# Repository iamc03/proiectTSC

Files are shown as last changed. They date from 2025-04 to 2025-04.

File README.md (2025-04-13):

# Proiect TSC
 ## Diagrama Bloc
 schema bloc

 ## Bill of Materials
 | Component       | Datasheet       | Link           |
 |-----------------|-----------------|----------------|
 | ESP32-C6-WROOM-1-N8 | - | https://www.snapeda.com/parts/ESP32-C6-WROOM-1-N8/Espressif+Systems/view-part/?ref=eda |
 | CPH3225A | - | https://www.snapeda.com/parts/CPH3225A/Seiko+Instruments/view-part/?ref=eda |
 | DS3231SN# | - | https://www.snapeda.com/parts/DS3231SN%23/Analog+Devices/view-part/?ref=eda |
 | MAX17048G+T10 | - | https://www.snapeda.com/parts/MAX17048G+T10/Analog+Devices/view-part/?ref=eda|
 | MBR0530 | - | https://www.snapeda.com/parts/MBR0530/Onsemi/view-part/?ref=eda |
 | PGB1010603MR | - | https://www.snapeda.com/parts/PGB1010603MR/Littelfuse/view-part/?ref=eda |
 | USBLC6-2SC6Y | - | https://www.snapeda.com/parts/USBLC6-2SC6Y/STMicroelectronics/view-part/?ref=eda |
 | W25Q512JVEIQ | - | https://www.snapeda.com/parts/W25Q512JVEIQ/Winbond+Electronics/view-part/?ref=eda |
 | 640-USB4110-GF-A | - | https://www.mouser.co.uk/ProductDetail/GCT/USB4110-GF-A?qs=KUoIvG%2F9IlYiZvIXQjyJeA%3D%3D |
 | PGB1010603MR | - | https://www.snapeda.com/parts/PGB1010603MR/Littelfuse/view-part/?ref=snap |
 | BUTTONS | - | https://industry.panasonic.com/global/en/products/control/switch/light-touch/number/evqpuj02k |
 | C (1-10) | - | https://componentsearchengine.com/part-view/CC0402MRX5R5BB106/YAGEO |
 | LED | - | https://www.snapeda.com/parts/KP-1608SURCK/Kingbright/view-part/?ref=search&t=LED%200603 |
 | D (1-12) | - | https://www.snapeda.com/parts/PGB1010603MR/Littelfuse/view-part/?ref=eda |
 | R (1-15) | - | https://componentsearchengine.com/part-view/R0402%201%25%20100%20K%20(RC0402FR-07100KL)/YAGEO |
 | Test Pads | - | - |
   
## Funcționalitate hardware
### Alimentare și încărcare
Conector USB + MCP73831: Permite încărcarea unei baterii LiPo prin USB.

LDO (ME6211 sau similar): Reglează tensiunea la 3.3V pentru alimentarea circuitului digital.

Condensatori de decuplare: Plasați strategic pentru stabilizarea alimentării.

### ESP32-C6
Modul WiFi/BLE cu capabilități de conectare și procesare date.

Flash: 4MB / RAM: 512KB.

GPIO multiple folosite pentru comunicații (SPI, I2C) și control periferice.

### E-Ink Display
Controlat prin SPI.

GPIO-uri adiționale pentru semnale de control (busy, reset).

### Protecții
Diodă Schottky (ex: MBR0530) pentru protecție polaritate inversă.

PTC resetabil pentru protecție curent.

### EEPROM / MEMS
EEPROM pentru păstrarea datelor între cicluri de alimentare (presupus U3).

MAX17048 pentru monitorizarea nivelului bateriei (comunicare I2C).

| Pin ESP32-C6 |	Funcție hardware |
|---|---|
| IO0 |	GPIO / Boot	|
| IO1 |	UART TX |
| IO2 |	UART RX	|
| IO3 |	GPIO	|
| IO4 | GPIO	|
| IO5 |	GPIO	|
| IO6 |	GPIO	|
| IO7 |	GPIO	|
| IO8 |	GPIO	|
| IO9 |	SPI Flash – IO2 |
| IO10 | 	SPI Flash – IO3 |
| IO11 |	SPI Flash – SCK |
| IO12 |	SPI Flash – CS |
| IO13 |	SPI Flash – IO1 |
| IO14 |	SPI Flash – IO0 |
| IO15 |	I2C SDA |
| IO16 |	I2C SCL |
| IO17 |	SPI Display – DC |
| IO18 |	SPI Display – RST |
| IO19 |	SPI Display – CS |
| IO20 |	SPI Display – CLK |
| IO21 |	SPI Display – MOSI |
| IO22 |	SPI Display – BUSY |
| IO23 |	SPI ESD / Qwiic |

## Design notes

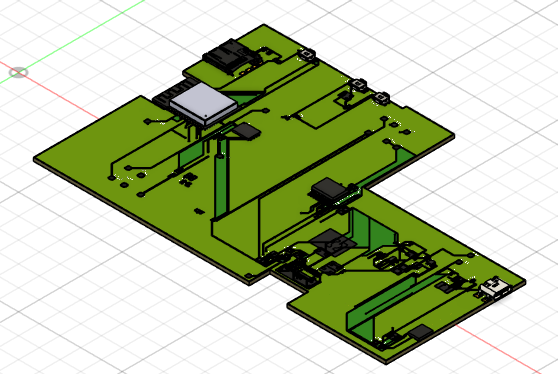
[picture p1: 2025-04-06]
Images/placa.png

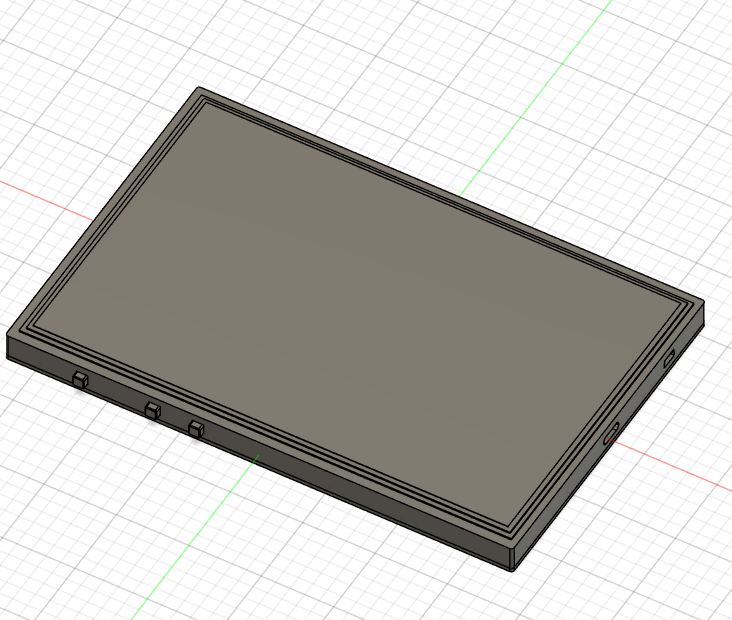
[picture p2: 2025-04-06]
Images/openbook.png

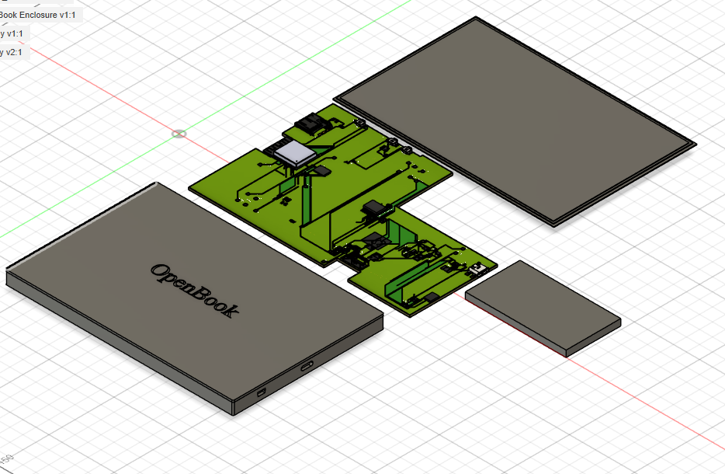
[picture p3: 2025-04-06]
Images/exploded.png

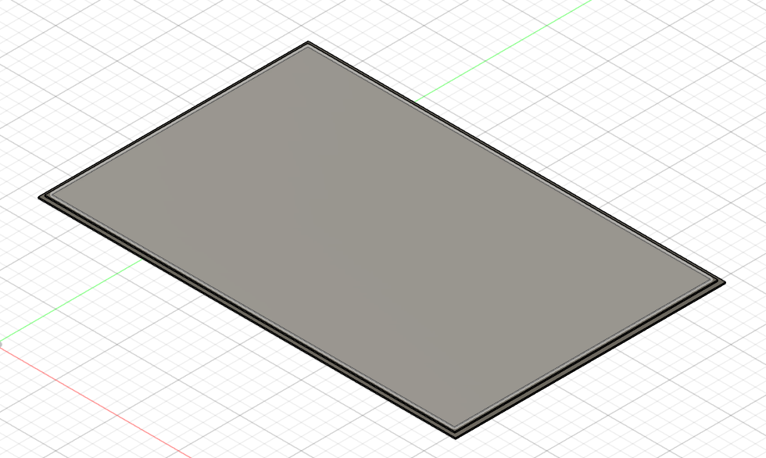
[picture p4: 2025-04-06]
Images/display.png

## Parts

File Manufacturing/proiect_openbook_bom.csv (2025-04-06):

Qty | Value | Device | Package | Parts | Description | ARROW_PART_NUMBER | ARROW_PRICE-STOCK | AVAILABILITY | CENTROID_NOT_SPECIFIED | CHECK_PRICES | COPYRIGHT | DATASHEET | DESCRIPTION | DIGIKEY_DESCRIPTION | DIGIKEY_PART_NUMBER | HEIGHT | LEAD_FREE | MANUFACTURER_NAME | MANUFACTURER_PART_NUMBER | MF | MFR_NAME | MOUSER_PART_NUMBER | MOUSER_PRICE-STOCK | MOUSER_TESTING_PART_NUMBER | MOUSER_TESTING_PRICE-STOCK | MP | MPN | PACKAGE | POPULARITY | PREFIX | PRICE | PROD_ID | PURCHASE-URL | ROHS | SNAPEDA_LINK | SPICEMODEL | SPICEPREFIX | TEMPERATURE_RANGE_HIGH | TEMPERATURE_RANGE_LOW | TP_SIGNAL_NAME | VALUE
1 |  | ADAFRUIT_LEDCHIP-LED0603 | ADAFRUIT_CHIP-LED0603 | LED1 | LED
1 |  | SJ | SJ | SJ1 | SMD solder JUMPER |  |  |  |  |  |  |  |  |  |  |  |  |  |  |  |  |  |  |  |  |  |  |  | 3
1 | 0.1uF/50V | ESP32_WROVER_EAGLE-LTSPICE_CC0402 | ESP32_WROVER_EAGLE-LTSPICE_C0402 | C18 | CAPACITOR, European symbol |  |  |  |  |  |  |  |  |  |  |  |  |  |  |  |  |  |  |  |  |  |  |  |  |  |  |  |  |  |  | NONE | C
1 | 0.47 | ESP32_WROVER_EAGLE-LTSPICE_RR0402 | ESP32_WROVER_EAGLE-LTSPICE_R0402 | R9 | RESISTOR, European symbol |  |  |  |  |  |  |  |  |  |  |  |  |  |  |  |  |  |  |  |  |  |  |  |  |  |  |  |  |  |  | NONE | R
1 | 100K | ESP32_WROVER_EAGLE-LTSPICE_RR0402 | ESP32_WROVER_EAGLE-LTSPICE_R0402 | R4 | RESISTOR, European symbol |  |  |  |  |  |  |  |  |  |  |  |  |  |  |  |  |  |  |  |  |  |  |  |  |  |  |  |  |  |  | NONE | R
8 | 100nF | ESP32_WROVER_EAGLE-LTSPICE_CC0402 | ESP32_WROVER_EAGLE-LTSPICE_C0402 | C1, C6, C21, C22, C23, C25, C26, C27 | CAPACITOR, European symbol |  |  |  |  |  |  |  |  |  |  |  |  |  |  |  |  |  |  |  |  |  |  |  |  |  |  |  |  |  |  | NONE | C
1 | 100uF | RCL_CPOL-EUCT3528 | RCL_CT3528 | C5 | POLARIZED CAPACITOR, European symbol |  |  |  |  |  |  |  |  |  |  |  |  |  |  |  |  |  |  |  |  |  |  |  | 0 |  |  |  |  |  |  |  | C
16 | 10K | ESP32_WROVER_EAGLE-LTSPICE_RR0402 | ESP32_WROVER_EAGLE-LTSPICE_R0402 | R5, R8, R12, R13, R14, R15, R16, R17, R19, R20, R21, R22, R23, R24, R25, R26 | RESISTOR, European symbol |  |  |  |  |  |  |  |  |  |  |  |  |  |  |  |  |  |  |  |  |  |  |  |  |  |  |  |  |  |  | NONE | R
1 | 10uF | ESP32_WROVER_EAGLE-LTSPICE_CC0402 | ESP32_WROVER_EAGLE-LTSPICE_C0402 | C10 | CAPACITOR, European symbol |  |  |  |  |  |  |  |  |  |  |  |  |  |  |  |  |  |  |  |  |  |  |  |  |  |  |  |  |  |  | NONE | C
1 | 112A-TAAR-R03_ATTEND | 112A-TAAR-R03_ATTEND | 112ATAARR03ATTEND | J2 | Micro SD Card Socket, Push-Push Type, Top Mount, SMT, H=1.83mm, 10u |  |  |  |  |  |  |  | Micro SD Card Socket | Push-Push Type | Top Mount | SMT | H=1.83mm | 10u |  |  | 1.9mm |  | ATTEND | 112A-TAAR-R03 ATTEND
1 | 15 | ESP32_WROVER_EAGLE-LTSPICE_RR0402 | ESP32_WROVER_EAGLE-LTSPICE_R0402 | R18 | RESISTOR, European symbol |  |  |  |  |  |  |  |  |  |  |  |  |  |  |  |  |  |  |  |  |  |  |  |  |  |  |  |  |  |  | NONE | R
1 | 1uF | ESP32_WROVER_EAGLE-LTSPICE_CC0402 | ESP32_WROVER_EAGLE-LTSPICE_C0402 | C24 | CAPACITOR, European symbol |  |  |  |  |  |  |  |  |  |  |  |  |  |  |  |  |  |  |  |  |  |  |  |  |  |  |  |  |  |  | NONE | C
9 | 1uF/50V | ESP32_WROVER_EAGLE-LTSPICE_CC0402 | ESP32_WROVER_EAGLE-LTSPICE_C0402 | C11, C12, C13, C14, C15, C16, C17, C19, C20 | CAPACITOR, European symbol |  |  |  |  |  |  |  |  |  |  |  |  |  |  |  |  |  |  |  |  |  |  |  |  |  |  |  |  |  |  | NONE | C
1 | 2.2 | ESP32_WROVER_EAGLE-LTSPICE_RR0402 | ESP32_WROVER_EAGLE-LTSPICE_R0402 | R10 | RESISTOR, European symbol |  |  |  |  |  |  |  |  |  |  |  |  |  |  |  |  |  |  |  |  |  |  |  |  |  |  |  |  |  |  | NONE | R
1 | 200 | ESP32_WROVER_EAGLE-LTSPICE_RR0402 | ESP32_WROVER_EAGLE-LTSPICE_R0402 | R6 | RESISTOR, European symbol |  |  |  |  |  |  |  |  |  |  |  |  |  |  |  |  |  |  |  |  |  |  |  |  |  |  |  |  |  |  | NONE | R
2 | 20V/4.2A/52mO/1.4W | ESP32_WROVER_SPARKFUN-DISCRETESEMI_MOSFET_PCH-DMG2305UX-7 | ESP32_WROVER_SPARKFUN-DISCRETESEMI_SOT23-3 | Q1, Q3 | P-channel MOSFETs |  |  |  |  |  |  |  |  |  |  |  |  |  |  |  |  |  |  |  |  |  |  |  |  |  |  | TRAN-14388 |  |  |  |  |  |  |  |  | 20V/4.2A/52mO/1.4W
1 | 2K | ESP32_WROVER_EAGLE-LTSPICE_RR0402 | ESP32_WROVER_EAGLE-LTSPICE_R0402 | R7 | RESISTOR, European symbol |  |  |  |  |  |  |  |  |  |  |  |  |  |  |  |  |  |  |  |  |  |  |  |  |  |  |  |  |  |  | NONE | R
2 | 4.7uF | EAGLE-LTSPICE_CC0402 | EAGLE-LTSPICE_C0402 | C3, C4 | CAPACITOR, European symbol |  |  |  |  |  |  |  |  |  |  |  |  |  |  |  |  |  |  |  |  |  |  |  |  |  |  |  |  |  |  | NONE | C
3 | 4.7uF | ESP32_WROVER_EAGLE-LTSPICE_CC0402 | ESP32_WROVER_EAGLE-LTSPICE_C0402 | C2, C7, C8 | CAPACITOR, European symbol |  |  |  |  |  |  |  |  |  |  |  |  |  |  |  |  |  |  |  |  |  |  |  |  |  |  |  |  |  |  | NONE | C
1 | 4.7uF/25V | ESP32_WROVER_EAGLE-LTSPICE_CC0402 | ESP32_WROVER_EAGLE-LTSPICE_C0402 | C9 | CAPACITOR, European symbol |  |  |  |  |  |  |  |  |  |  |  |  |  |  |  |  |  |  |  |  |  |  |  |  |  |  |  |  |  |  | NONE | C
2 | 5k1 | ESP32_WROVER_EAGLE-LTSPICE_RR0402 | ESP32_WROVER_EAGLE-LTSPICE_R0402 | R2, R3 | RESISTOR, European symbol |  |  |  |  |  |  |  |  |  |  |  |  |  |  |  |  |  |  |  |  |  |  |  |  |  |  |  |  |  |  | NONE | R
1 | 68uH | 744043680IND_4828-WE-TPC_WRE | IND_4828-WE-TPC_WRE | L1 |  |  |  |  |  |  | Copyright (C) 2024 Ultra Librarian. All rights reserved. |  |  |  |  |  |  |  | 744043680 |  | Wurth Electronics
1 | BD5229G-TR | BD5229G-TR | SOT95P280X125-5N | IC2 | Voltage Detector with Adjustable Delay Time: CMOS processes are utilized to develop high precision, low current consumption CMOS reset ICs that allow arbitrary setting of the delay time. The extensive lineup includes both Nch Open Drain and CMOS output types in a wide range of detection voltages (from 2.3V to 6.0V, in 0.1V steps), enabling selection of the ideal solution based on customer requirements. In addition, the entire series is of course both lead-free and RoHS-compliant. |  |  |  |  |  |  |  | Voltage Detector with Adjustable Delay Time: CMOS processes are utilized to develop high precision | low current consumption CMOS reset ICs that allow arbitrary setting of the delay time. The extensive lineup includes both Nch Open Drain and CMOS output types in a wide range of detection voltages (from 2.3V to 6.0V | in 0.1V steps) | enabling selection of the ideal solution based on customer requirements. In addition | the entire series is of course both lead-free and RoHS-compliant. |  |  | 1.25mm |  | ROHM Semiconductor | BD5229G-TR |  |  | 755-BD5229G-TR | https://www.mouser.co.uk/ProductDetail/ROHM-Semiconductor/BD5229G-TR?qs=4kLU8WoGk0vvnhrrYwdszw%3D%3D
3 | BUTTON_CUSYOMV1 | BUTTON_CUSYOMV1 | MYBUTTON | U$1, U$2, U$3
1 | CPH3225A | CPH3225A | CAPCP3225X100N | C28 | Cap 0.011F 3.3V 1210 Flat Check availability |  |  | Not in stock |  | https://www.snapeda.com/parts/CPH3225A/Seiko+Instruments/view-part/?ref=eda |  |  | 11 mF (EDLC) Supercapacitor 3.3 V 1210 (3225 Metric) - - |  |  |  |  |  |  | Seiko Instruments |  |  |  |  |  | CPH3225A |  | 1210 Seiko |  |  | None |  | https://www.snapeda.com/api/url_track_click_mouser/?unipart_id=562593&manufacturer=Seiko Instruments&part_name=CPH3225A&search_term=None |  | https://www.snapeda.com/parts/CPH3225A/Seiko+Instruments/view-part/?ref=snap
1 | DS3231SN# | DS3231SN# | SOIC127P1032X265-16N | U5 | Real Time Clock Serial 16-Pin SOIC W T/R Check availability |  |  | In Stock |  | https://www.snapeda.com/parts/DS3231SN%23/Analog+Devices/view-part/?ref=eda |  |  | Extremely Accurate I²C-Integrated RTC/TCXO/Crystal |  |  |  |  |  |  | Analog Devices |  |  |  |  |  | DS3231SN# |  | SOIC-16 Maxim |  |  | None |  | https://www.snapeda.com/api/url_track_click_mouser/?unipart_id=99048&manufacturer=Analog Devices&part_name=DS3231SN#&search_term=None |  | https://www.snapeda.com/parts/DS3231SN%23/Analog+Devices/view-part/?ref=snap
1 | ESP32-C6-WROOM-1-N8 | ESP32-C6-WROOM-1-N8 | XCVR_ESP32-C6-WROOM-1-N8 | U1 | Check availability |  |  | In Stock |  | https://www.snapeda.com/parts/ESP32-C6-WROOM-1-N8/Espressif+Systems/view-part/?ref=eda |  |  | Multiprotocol Modules ESP32-C6 module | Wi-Fi 6 in 2.4 GHz band | Bluetooth 5 | Zigbee 3.0 and Thread. ESP34-WROOM Compatible - ENGINEERING SAMPLE |  |  |  |  |  |  | Espressif Systems |  |  |  |  |  | ESP32-C6-WROOM-1-N8 |  | None |  |  | None |  |  |  | https://www.snapeda.com/parts/ESP32-C6-WROOM-1-N8/Espressif+Systems/view-part/?ref=snap
1 | ESP32C6_VARISTORCN1812 | ESP32C6_VARISTORCN1812 | ESP32C6_VARISTOR_CT/CN1812 | R1 | VARISTOR |  |  |  |  |  |  |  |  |  |  |  |  |  |  |  |  |  |  |  |  |  |  |  | 0
2 | ESP32_WROVER_AVX---SD0805S020S1R0_AVX_SD0805S020S1R0_0_0AVX_SD0805S020S1R0_0_0 | ESP32_WROVER_AVX---SD0805S020S1R0_AVX_SD0805S020S1R0_0_0AVX_SD0805S020S1R0_0_0 | ESP32_WROVER_AVX---SD0805S020S1R0_AVX_SD0805S020S1R0_0 | D2, D6 | Schottky Barrier Rectifier Diode |  |  |  | No |  |  | http://datasheets.avx.com/schottky.pdf |  | DIODE SCHOTTKY 20V 1A 0805 | 478-7800-1-ND |  | yes |  |  | AVX |  | 581-SD0805S020S1R0 |  |  |  |  |  | 0805 (2012 metric) |  | D |  |  |  | yes |  |  |  | +125°C | -55°C
1 | ESP32_WROVER_BME680_BME680 | ESP32_WROVER_BME680_BME680 | ESP32_WROVER_BME680_PSON80P300X300X100-8N | U3 | Integrated Environmental Unit |  |  | Unavailable |  |  |  |  | Integrated Environmental Unit |  |  |  |  |  |  | Bosch Sensortec |  |  |  |  |  | BME680 |  | LGA-8 Bosch Tools |  |  | None
1 | ESP32_WROVER_SPARKFUN-IC-POWER_MCP73831 | ESP32_WROVER_SPARKFUN-IC-POWER_MCP73831 | ESP32_WROVER_SPARKFUN-IC-POWER_SOT23-5 | U2 | MCP73831T Li-Ion, Li-Pol Controller |  |  |  |  |  |  |  |  |  |  |  |  |  |  |  |  |  |  |  |  |  |  |  |  |  |  | IC-09995
1 | FH34SRJ-24S-0.5SH_99_ | FH34SRJ-24S-0.5SH_99_ | FH34SRJ24S05SH99 | J3 | (0.50mm) Surface Mount, Right Angle |  |  |  |  |  |  |  | 24 Position FFC | FPC Connector Contacts | (0.50mm) Surface Mount | Right Angle |  |  | 1.1mm |  | Hirose | FH34SRJ-24S-0.5SH(99) |  |  | 798-FH34SRJ24S05SH99 | https://www.mouser.co.uk/ProductDetail/Hirose-Connector/FH34SRJ-24S-0.5SH99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
1 | MAX17048G+T10 | MAX17048G+T10 | SON50P200X200X80-9N | U4 | Check availability |  |  | In Stock |  | https://www.snapeda.com/parts/MAX17048G+T10/Analog+Devices/view-part/?ref=eda |  |  | 3µA 1-Cell/2-Cell Fuel Gauge with ModelGauge |  |  |  |  |  |  | Analog Devices |  |  |  |  |  | MAX17048G+T10 |  | TDFN-8 Maxim |  |  | None |  | https://www.snapeda.com/api/url_track_click_mouser/?unipart_id=329239&manufacturer=Analog Devices&part_name=MAX17048G+T10&search_term=None |  | https://www.snapeda.com/parts/MAX17048G+T10/Analog+Devices/view-part/?ref=snap
3 | MBR0530 | MBR0530 | SOD3716X135N | D3, D4, D5 | ON SEMICONDUCTOR - MBR0530 - DIODE, SCHOTTKY, 0.5A, 30V, SOD-123 |  |  | In Stock |  | https://www.snapeda.com/parts/MBR0530/Onsemi/view-part/?ref=eda |  |  | Diode Schottky 30 V 500mA Surface Mount SOD-123 |  |  |  |  |  |  | ON Semiconductor |  |  |  |  |  | MBR0530 |  | SOD-123-2 ON Semiconductor |  |  | None |  | https://www.snapeda.com/api/url_track_click_mouser/?unipart_id=179458&manufacturer=ON Semiconductor&part_name=MBR0530&search_term=None |  | https://www.snapeda.com/parts/MBR0530/Onsemi/view-part/?ref=snap
6 | PGB1010603MR | PGB1010603MR | DIOC1608X36N | D7, D8, D9, D10, D11, D12 | Check availability |  |  | In Stock |  | https://www.snapeda.com/parts/PGB1010603MR/Littelfuse/view-part/?ref=eda |  |  | 150V (Typ) Clamp - Ipp Tvs Diode Surface Mount 0603 (1608 Metric) |  |  |  |  |  |  | Littelfuse Inc. |  |  |  |  |  | PGB1010603MR |  | 0603 Littelfuse Inc. |  |  | None |  | https://www.snapeda.com/api/url_track_click_mouser/?unipart_id=5659453&manufacturer=Littelfuse Inc.&part_name=PGB1010603MR&search_term=None |  | https://www.snapeda.com/parts/PGB1010603MR/Littelfuse/view-part/?ref=snap
1 | QWIIC_RIGHT_ANGLE | QWIIC_CONNECTORJS-1MM | JST04_1MM_RA | J4 | SparkFun I2C Standard Qwiic Connector |  |  |  |  |  |  |  |  |  |  |  |  |  |  |  |  |  |  |  |  |  |  |  |  |  |  | CONN-13694 |  |  |  |  |  |  |  |  | QWIIC_RIGHT_ANGLE
1 | SAMACSYS_PARTS_USB4110-GF-A | SAMACSYS_PARTS_USB4110-GF-A | SAMACSYS_PARTS_USB4110GFA | J1 | CONN USB 2.0 TYPE-C R/A SMT |  |  |  |  |  |  |  | CONN USB 2.0 TYPE-C R/A SMT |  |  | 3.26mm |  | GCT (GLOBAL CONNECTOR TECHNOLOGY) | USB4110-GF-A |  |  | 640-USB4110-GF-A | https://www.mouser.co.uk/ProductDetail/GCT/USB4110-GF-A?qs=KUoIvG%2F9IlYiZvIXQjyJeA%3D%3D
1 | SI1308EDL-T1-GE3 | SI1308EDL-T1-GE3 | SOT65P210X110-3N | Q2 | MOSFET N-Ch 30V 1.5A TrenchFET SC70 Vishay Si1308EDL-T1-GE3 N-channel MOSFET Transistor, 1.5 A, 30 V, 3-Pin SC-70 |  |  | In Stock |  | https://www.snapeda.com/parts/SI1308EDL-T1-GE3/Vishay+Siliconix/view-part/?ref=eda |  |  | Si1308EDL-T1-GE3 N-channel MOSFET Transistor | 1.5 A | 30 V | 3-Pin SC-70 | Siliconix / Vishay SI1308EDL-T1-GE3 |  |  |  |  |  |  | Vishay Siliconix |  |  |  |  |  | SI1308EDL-T1-GE3 |  | SOT-323 Vishay Semiconductor |  |  | None |  | https://www.snapeda.com/api/url_track_click_mouser/?unipart_id=274603&manufacturer=Vishay Siliconix&part_name=SI1308EDL-T1-GE3&search_term=None |  | https://www.snapeda.com/parts/SI1308EDL-T1-GE3/Vishay+Siliconix/view-part/?ref=snap
17 | TPTP20R | TPTP20R | TP20R | TP1, TP2, TP3, TP4, TP5, TP6, TP7, TP9, TP10, TP11, TP12, TP13, TP14, TP15, TP16, TP17, TP18 | Test pad |  |  |  |  |  |  |  |  |  |  |  |  |  |  |  |  |  |  |  |  |  |  |  | 2
1 | USBLC6-2SC6Y | USBLC6-2SC6Y | SOT95P280X145-6N | D1 | Low Cap. ESD Protection Auto SOT-23-6 STMicroelectronics USBLC6-2SC6Y, Dual Uni-Directional TVS Diode Array, 6-Pin SOT-23 |  |  | In Stock |  | https://www.snapeda.com/parts/USBLC6-2SC6Y/STMicroelectronics/view-part/?ref=eda |  |  | 17V Clamp 5A (8/20µs) Ipp Tvs Diode Surface Mount SOT-23-6 |  |  |  |  |  |  | STMicroelectronics |  |  |  |  |  | USBLC6-2SC6Y |  | SOT-23-6 STMicroelectronics |  |  | None |  |  |  | https://www.snapeda.com/parts/USBLC6-2SC6Y/STMicroelectronics/view-part/?ref=snap
1 | W25Q512JVEIQ | W25Q512JVEIQ | SON127P600X800X80-9N | U6 | Check availability |  |  | In Stock |  | https://www.snapeda.com/parts/W25Q512JVEIQ/Winbond+Electronics/view-part/?ref=eda |  |  | FLASH - NOR Memory IC 512Mb (64M x 8) SPI - Quad I/O 133 MHz 8-WSON (8x6) |  |  |  |  |  |  | Winbond Electronics |  |  |  |  |  | W25Q512JVEIQ |  | Package |  |  | None |  |  |  | https://www.snapeda.com/parts/W25Q512JVEIQ/Winbond+Electronics/view-part/?ref=snap
1 | XC6220A331MR-G | XC6220A331MR-G | SOT95P280X120-5N | IC1 | LDO Voltage Regulators |  |  |  |  |  |  |  | LDO Voltage Regulators |  |  | 1.2mm |  | Torex | XC6220A331MR-G |  |  | 865-XC6220A331MR-G | https://www.mouser.co.uk/ProductDetail/Torex-Semiconductor/XC6220A331MR-G?qs=AsjdqWjXhJ8ZSWznL1J0gg%3D%3D

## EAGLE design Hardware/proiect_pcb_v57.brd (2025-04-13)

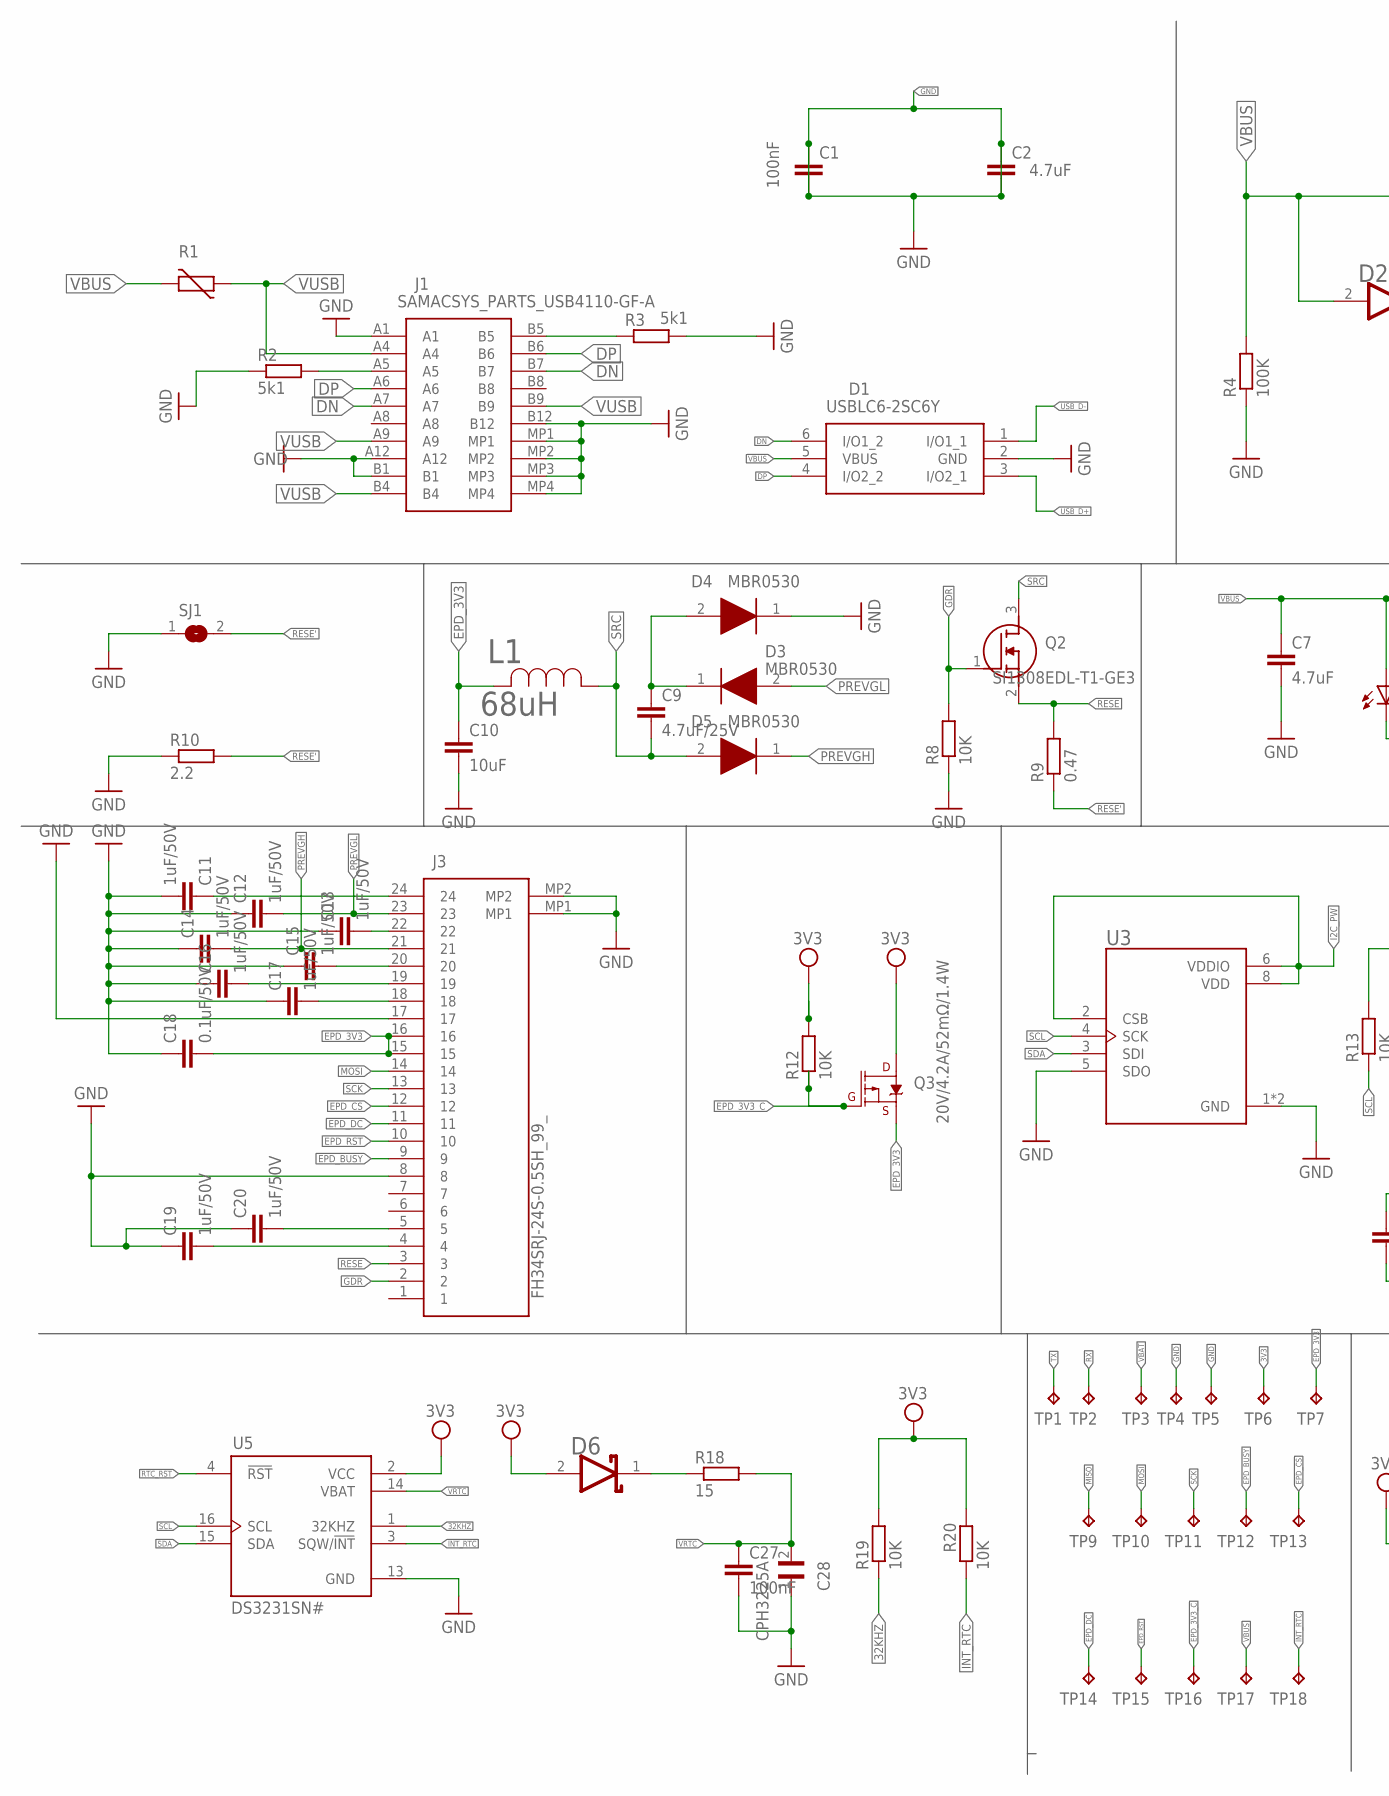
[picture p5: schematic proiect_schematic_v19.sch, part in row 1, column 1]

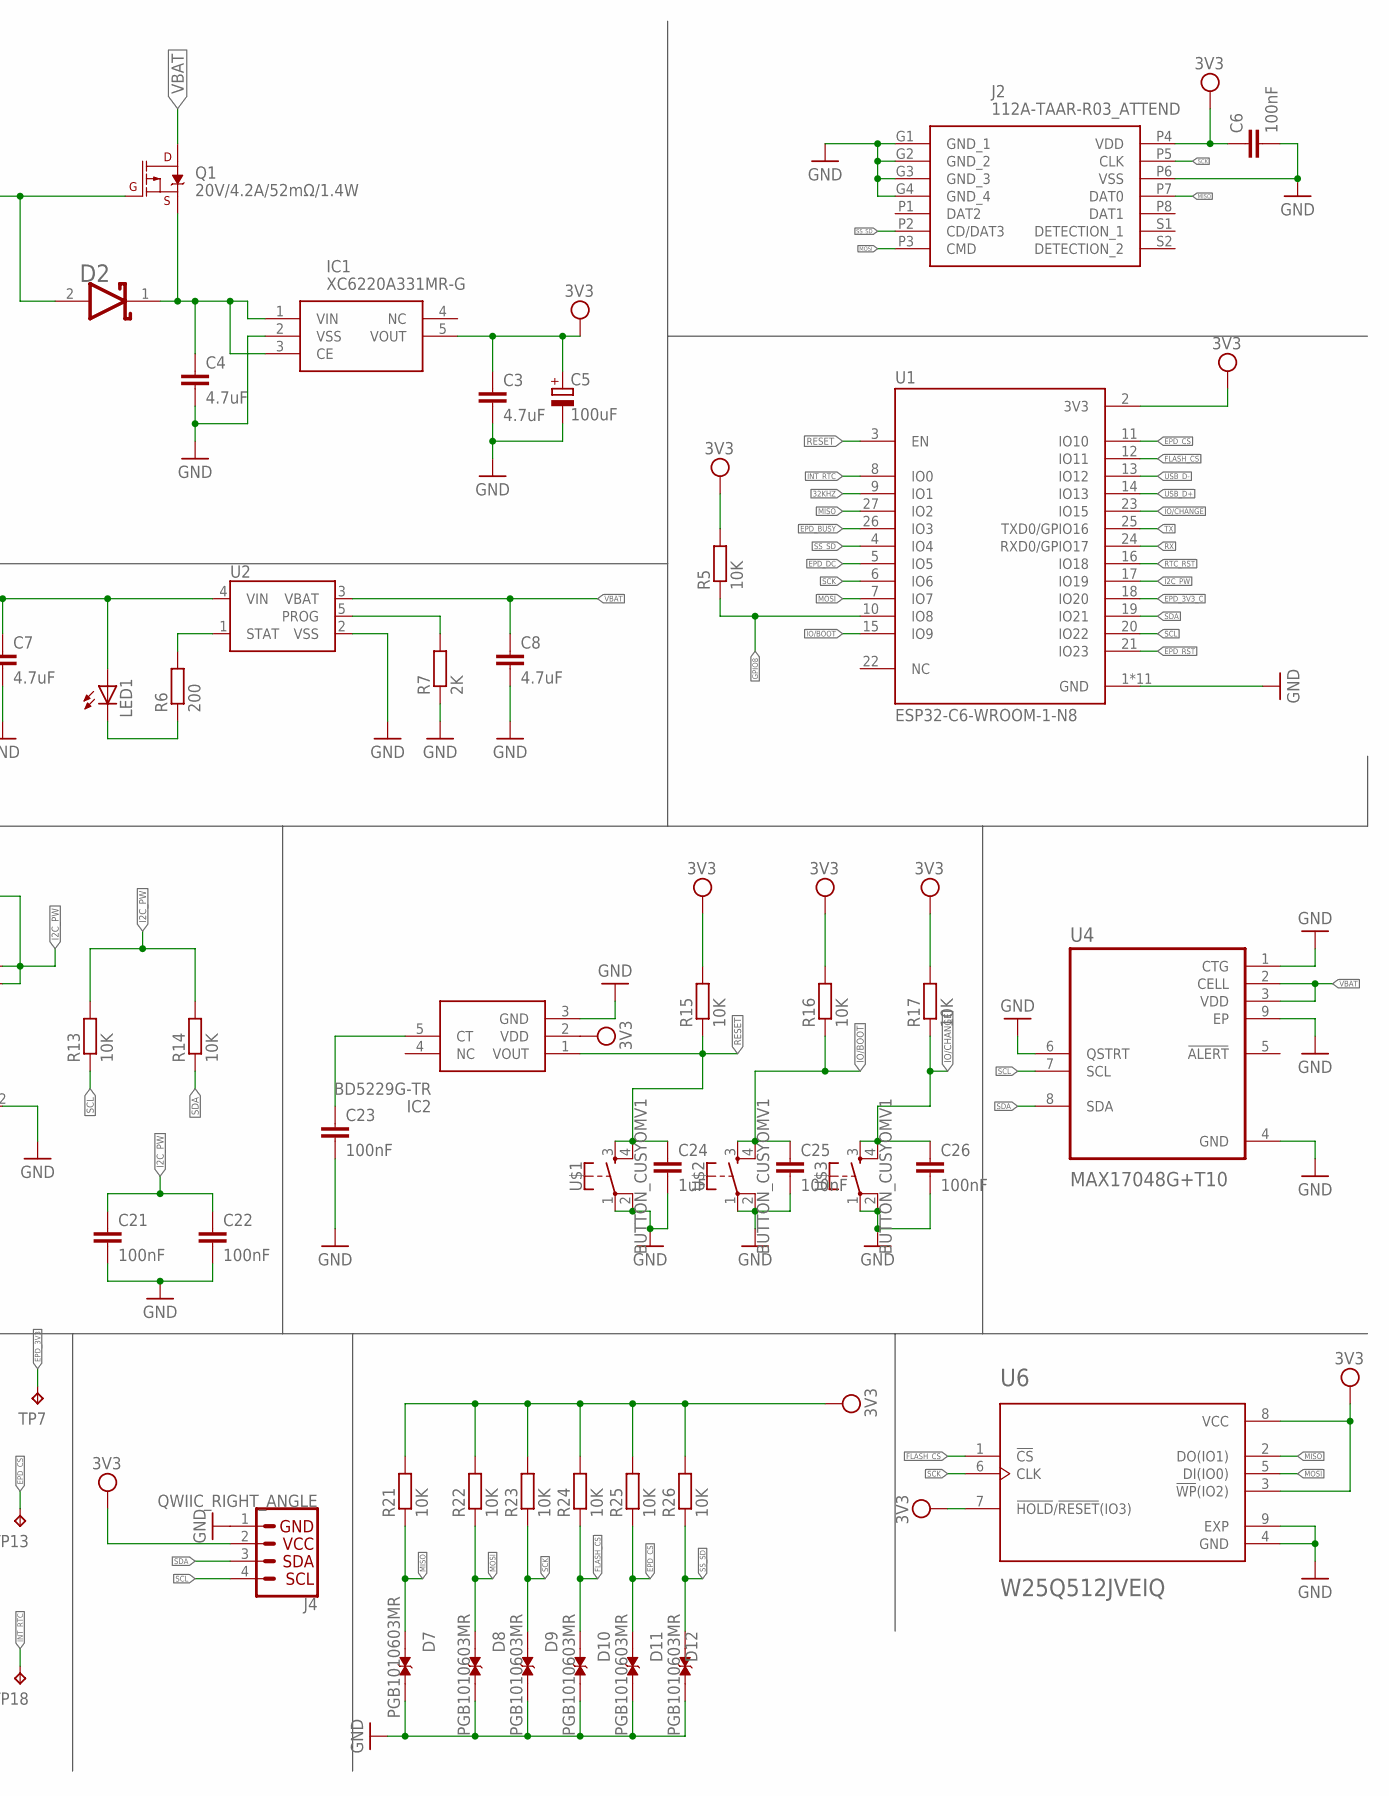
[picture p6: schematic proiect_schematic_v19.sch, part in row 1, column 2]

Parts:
C1, C6, C21, C22, C23, C25, C26, C27: 100nF; ESP32_WROVER_EAGLE-LTSPICE_C0402
C2, C7, C8: 4.7uF; ESP32_WROVER_EAGLE-LTSPICE_C0402
C3, C4: 4.7uF; EAGLE-LTSPICE_C0402
C5: 100uF; RCL_CT3528
C9: 4.7uF/25V; ESP32_WROVER_EAGLE-LTSPICE_C0402
C10: 10uF; ESP32_WROVER_EAGLE-LTSPICE_C0402
C11, C12, C13, C14, C15, C16, C17, C19, C20: 1uF/50V; ESP32_WROVER_EAGLE-LTSPICE_C0402
C18: 0.1uF/50V; ESP32_WROVER_EAGLE-LTSPICE_C0402
C24: 1uF; ESP32_WROVER_EAGLE-LTSPICE_C0402
C28: CPH3225A; CAPCP3225X100N
D1: USBLC6-2SC6Y; SOT95P280X145-6N
D2, D6: ESP32_WROVER_AVX---SD0805S020S1R0_AVX_SD0805S020S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; ESP32_WROVER_AVX---SD0805S020S1R0_AVX_SD0805S020S1R0_0
D3, D4, D5: MBR0530; SOD3716X135N
D7, D8, D9, D10, D11, D12: PGB1010603MR; DIOC1608X36N
IC1: XC6220A331MR-G; SOT95P280X120-5N
IC2: BD5229G-TR; SOT95P280X125-5N
J1: SAMACSYS_PARTS_USB4110-GF-A; SAMACSYS_PARTS_USB4110GFA
J2: 112A-TAAR-R03_ATTEND; 112ATAARR03ATTEND
J3: FH34SRJ-24S-0.5SH_99_; FH34SRJ24S05SH99
J4: QWIIC_RIGHT_ANGLE; JST04_1MM_RA
L1: 68uH; IND_4828-WE-TPC_WRE
LED1: ADAFRUIT_LEDCHIP-LED0603; ADAFRUIT_CHIP-LED0603
Q1, Q3: 20V/4.2A/52mΩ/1.4W; ESP32_WROVER_SPARKFUN-DISCRETESEMI_SOT23-3
Q2: SI1308EDL-T1-GE3; SOT65P210X110-3N
R1: ESP32C6_VARISTORCN1812; ESP32C6_VARISTOR_CT/CN1812
R2, R3: 5k1; ESP32_WROVER_EAGLE-LTSPICE_R0402
R4: 100K; ESP32_WROVER_EAGLE-LTSPICE_R0402
R5, R8, R12, R13, R14, R15, R16, R17, R19, R20, R21, R22, R23, R24, R25, R26: 10K; ESP32_WROVER_EAGLE-LTSPICE_R0402
R6: 200; ESP32_WROVER_EAGLE-LTSPICE_R0402
R7: 2K; ESP32_WROVER_EAGLE-LTSPICE_R0402
R9: 0.47; ESP32_WROVER_EAGLE-LTSPICE_R0402
R10: 2.2; ESP32_WROVER_EAGLE-LTSPICE_R0402
R18: 15; ESP32_WROVER_EAGLE-LTSPICE_R0402
SJ1: SJ
TP1, TP2, TP3, TP4, TP5, TP6, TP7, TP9, TP10, TP11, TP12, TP13, TP14, TP15, TP16, TP17, TP18: TPTP20R; TP20R
U1: ESP32-C6-WROOM-1-N8; XCVR_ESP32-C6-WROOM-1-N8
U2: ESP32_WROVER_SPARKFUN-IC-POWER_MCP73831; ESP32_WROVER_SPARKFUN-IC-POWER_SOT23-5
U3: ESP32_WROVER_BME680_BME680; ESP32_WROVER_BME680_PSON80P300X300X100-8N
U4: MAX17048G+T10; SON50P200X200X80-9N
U5: DS3231SN#; SOIC127P1032X265-16N
U6: W25Q512JVEIQ; SON127P600X800X80-9N
U$1, U$2, U$3: BUTTON_CUSYOMV1; MYBUTTON

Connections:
3V3: C3.1, C5.+, C6.1, D6.2 (ANODE), IC1.5 (VOUT), IC2.2 (VDD), J2.P4 (VDD), J4.2, Q3.3 (D), R5.2, R12.2, R15.2, R16.2, R17.2, R19.2, R20.2, R21.2, R22.2, R23.2, R24.2, R25.2, R26.2, TP6.TP, U1.2 (3V3), U5.2 (VCC), U6.3 (!WP!(IO2)), U6.7 (!HOLD!/!RESET!(IO3)), U6.8 (VCC)
32KHZ: R19.1, U1.9 (IO1), U5.1 (32KHZ)
DN: D1.6 (I/O1_2), J1.A7, J1.B7
DP: D1.4 (I/O2_2), J1.A6, J1.B6
EPD_3V3: C10.1, C18.2, J3.15, J3.16, L1.2, Q3.2 (S), TP7.TP
EPD_3V3_C: Q3.1 (G), R12.1, TP16.TP, U1.18 (IO20)
EPD_BUSY: J3.9, TP12.TP, U1.26 (IO3)
EPD_CS: D11.1, J3.12, R25.1, TP13.TP, U1.11 (IO10)
EPD_DC: J3.11, TP14.TP, U1.5 (IO5)
EPD_RST: J3.10, TP15.TP, U1.21 (IO23)
FLASH_CS: D10.1, R24.1, U1.12 (IO11), U6.1 (!CS)
GDR: J3.2, Q2.1 (G), R8.2
GND: C1.1, C1.2, C2.1, C2.2, C3.2, C4.2, C5.-, C6.2, C7.2, C8.2, C10.2, C11.2, C12.1, C13.1, C14.1, C15.1, C16.1, C17.1, C18.1, C19.1, C20.1, C21.2, C22.2, C23.2, C24.2, C25.2, C26.2, C27.2, C28.1, D1.2 (GND), D4.1 (K), D7.2, D8.2, D9.2, D10.2, D11.2, D12.2, IC1.2 (VSS), IC2.3 (GND), J1.A1, J1.A12, J1.B1, J1.B12, J1.MP1, J1.MP2, J1.MP3, J1.MP4, J2.G1 (GND_1), J2.G2 (GND_2), J2.G3 (GND_3), J2.G4 (GND_4), J2.P6 (VSS), J3.8, J3.17, J3.MP1, J3.MP2, J4.1, R2.1, R3.2, R4.1, R7.1, R8.1, R10.1, SJ1.1, TP4.TP, TP5.TP, U1.1 (GND), U1.28 (GND), U1.29_1 (GND), U1.29_2 (GND), U1.29_3 (GND), U1.29_4 (GND), U1.29_5 (GND), U1.29_6 (GND), U1.29_7 (GND), U1.29_8 (GND), U1.29_9 (GND), U2.2 (VSS), U3.1 (GND), U3.5 (SDO), U3.7 (GND), U4.1 (CTG), U4.4 (GND), U4.6 (QSTRT), U4.9 (EP), U5.13 (GND), U6.4 (GND), U6.9 (EXP), U$1.1, U$1.2, U$2.1, U$2.2, U$3.1, U$3.2
GPIO8: R5.1, U1.10 (IO8)
I2C_PW: C21.1, C22.1, R13.2, R14.2, U1.17 (IO19), U3.2 (CSB), U3.6 (VDDIO), U3.8 (VDD)
INT_RTC: R20.1, TP18.TP, U1.8 (IO0), U5.3 (SQW/!INT)
IO/BOOT: C25.1, R16.1, U1.15 (IO9), U$2.3, U$2.4
IO/CHANGE: C26.1, R17.1, U1.23 (IO15), U$3.3, U$3.4
MISO: D7.1, J2.P7 (DAT0), R21.1, TP9.TP, U1.27 (IO2), U6.2 (DO(IO1))
MOSI: D8.1, J2.P3 (CMD), J3.14, R22.1, TP10.TP, U1.7 (IO7), U6.5 (DI(IO0))
unnamed: J1.A5, R2.2
unnamed: J1.B5, R3.1
unnamed: C11.1, J3.24
unnamed: C4.1, D2.1 (CATHODE), IC1.1 (VIN), IC1.3 (CE), Q1.2 (S)
unnamed: R6.2, U2.1 (STAT)
unnamed: LED1.C, R6.1
unnamed: R7.2, U2.5 (PROG)
unnamed: C9.1, D3.1 (K), D4.2 (A)
unnamed: C13.2, J3.22
unnamed: C15.2, J3.20
unnamed: C16.2, J3.19
unnamed: C17.2, J3.18
unnamed: C19.2, J3.4
unnamed: C20.2, J3.5
unnamed: C23.1, IC2.5 (CT)
unnamed: D6.1 (CATHODE), R18.1
PREVGH: C14.2, D5.1 (K), J3.21
PREVGL: C12.2, D3.2 (A), J3.23
RESE: J3.3, Q2.2 (S), R9.2
RESE': R9.1, R10.2, SJ1.2
RESET: C24.1, IC2.1 (VOUT), R15.1, U1.3 (EN), U$1.3, U$1.4
RTC_RST: U1.16 (IO18), U5.4 (!RST)
RX: TP2.TP, U1.24 (RXD0/GPIO17)
SCK: D9.1, J2.P5 (CLK), J3.13, R23.1, TP11.TP, U1.6 (IO6), U6.6 (CLK)
SCL: J4.4, R13.1, U1.20 (IO22), U3.4 (SCK), U4.7 (SCL), U5.16 (SCL)
SDA: J4.3, R14.1, U1.19 (IO21), U3.3 (SDI), U4.8 (SDA), U5.15 (SDA)
SRC: C9.2, D5.2 (A), L1.1, Q2.3 (D)
SS_SD: D12.1, J2.P2 (CD/DAT3), R26.1, U1.4 (IO4)
TX: TP1.TP, U1.25 (TXD0/GPIO16)
USB_D+: D1.3 (I/O2_1), U1.14 (IO13)
USB_D-: D1.1 (I/O1_1), U1.13 (IO12)
VBAT: C8.1, Q1.3 (D), TP3.TP, U2.3 (VBAT), U4.2 (CELL), U4.3 (VDD)
VBUS: C7.1, D1.5 (VBUS), D2.2 (ANODE), LED1.A, Q1.1 (G), R1.2, R4.2, TP17.TP, U2.4 (VIN)
VRTC: C27.1, C28.2, R18.2, U5.14 (VBAT)
VUSB: J1.A4, J1.A9, J1.B4, J1.B9, R1.1

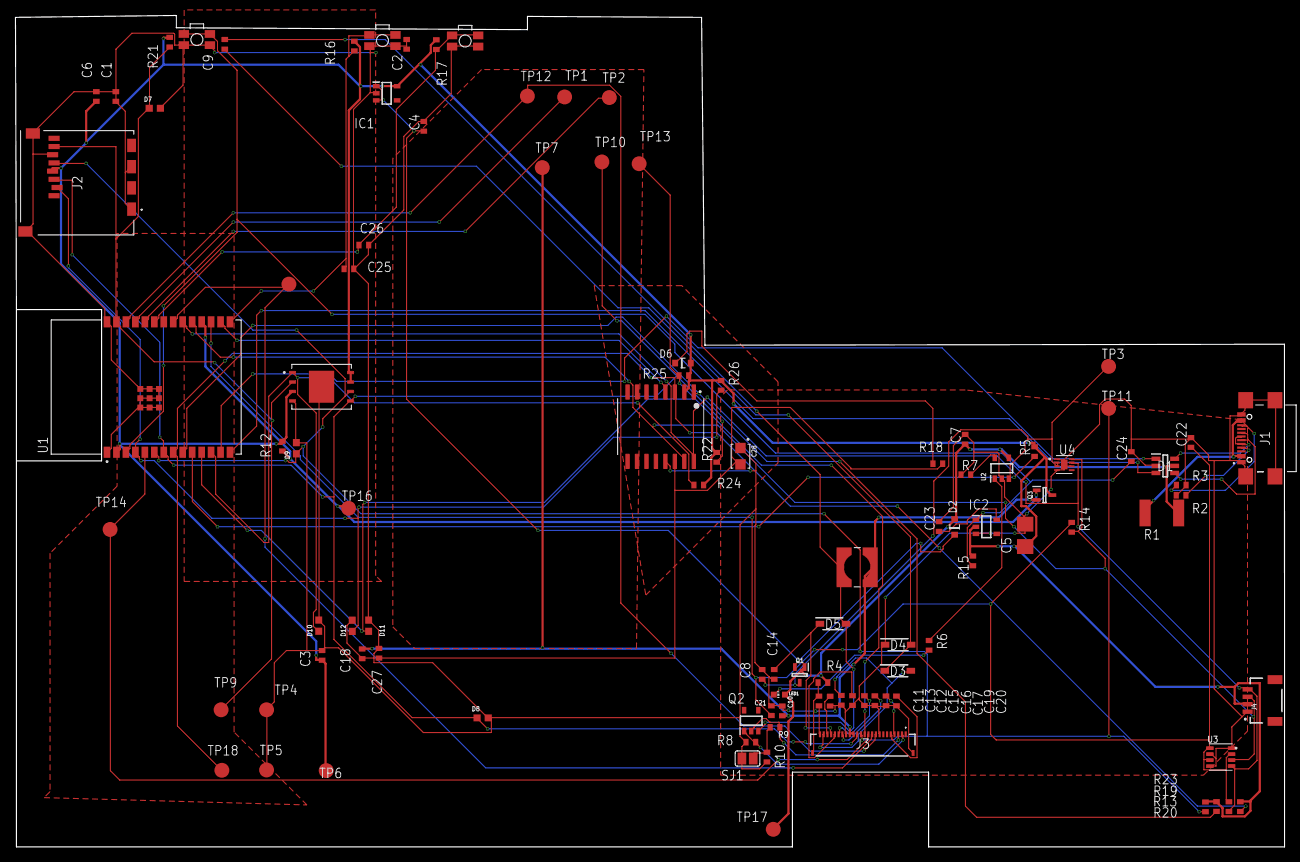
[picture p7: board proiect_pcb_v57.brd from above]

Board: 2 copper layers, 170.3 x 111.6 mm, 103 parts (0 on the bottom side), 55 nets.

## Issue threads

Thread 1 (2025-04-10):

Structura README

razvang05, 2025-04-10:
README-ul conține doar tabelul BOM (Bill of Materials), dar pentru a fi complet , ar mai trebui adăugate următoarele puncte:

1. **Diagramă bloc a proiectului**
   - Include toate componentele hardware (senzori, module, microcontroller, alimentare etc.) și relațiile dintre ele.
   - Poți folosi un model simplu (stil draw.io).

3. **Descrierea detaliată a funcționalității hardware**
   - Ce module/componente s-au folosit și ce rol au în proiect
   - Ce interfețe de comunicație folosesc (I2C, SPI, UART etc.)
   - Eventuale calcule de consum de energie (dacă sunt relevante)

4. **Maparea pinilor ESP32-C6**
   - Trebuie precizat clar ce pini sunt utilizați și pentru ce componentă

Closed 2025-04-13.

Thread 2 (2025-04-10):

Erori DRC

razvang05, 2025-04-10:
###  Erori DRC  identificate la componenta L1:

- **Copper Width **
  - Problema: Lățimea unor trasee nu respectă regula impusă pentru net class-ul `1 power`.
  - Soluție:
    - Verifică în meniul **Design Rules** lățimea minimă pentru net class-ul `power` apoi selectează traseele in neregula și modifică-le lățimea.
    - Poți folosi și comanda **Change Width**.

- **SMD Error – Net Class: 1 power** (stratul Top)
  - Problema: Conexiunea dintre un pad SMD și traseu nu respectă regulile (posibil din cauza lățimii).
  - Soluție:
    - Verifică conexiunea fizică între pad-ul SMD și traseu.

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

Closed 2025-04-13.

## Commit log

2025-04-12 Fix: Removed valori din silkscreen, issue #4
    [proiect_pcb_v24.brd]
2025-04-12 Rezolvat valori silkscreen, closes #4
    [proiect_pcb_v24.brd]
2025-04-12 Rezolvat right angles trasee, closes #3
    [proiect_pcb v26.brd]
2025-04-13 Rezolvat erori DRC, closes #2
    [proiect_pcb_v57.brd]
2025-04-13 Delete Hardware/proiect_pcb_v24.brd
    Old version
    [proiect_pcb_v24.brd]
2025-04-13 Delete Hardware/proiect_pcb v26.brd
    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
    [proiect_pcb v26.brd]
2025-04-13 Delete Hardware/proiect_pcb v22.brd
    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
    [proiect_pcb v22.brd]
2025-04-13 Delete Mechanical/OpenBook (design complet) v1.f3z
    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
    [OpenBook (design complet) v1.f3z]
2025-04-13 BOM complete in README

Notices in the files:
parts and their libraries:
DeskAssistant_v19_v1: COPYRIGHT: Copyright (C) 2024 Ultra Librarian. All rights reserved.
